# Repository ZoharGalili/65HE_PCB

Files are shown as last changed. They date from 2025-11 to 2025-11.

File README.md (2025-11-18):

# 65HE_PCB

this is a 65% hall effect keyboard pcb running [libhmk](https://github.com/peppapighs/libhmk) firmware.

## Board Renders

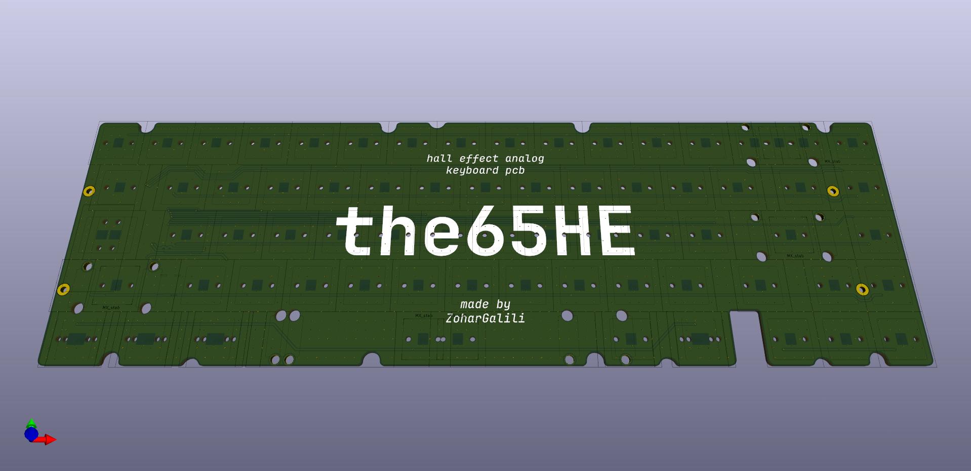
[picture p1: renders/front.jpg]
Render

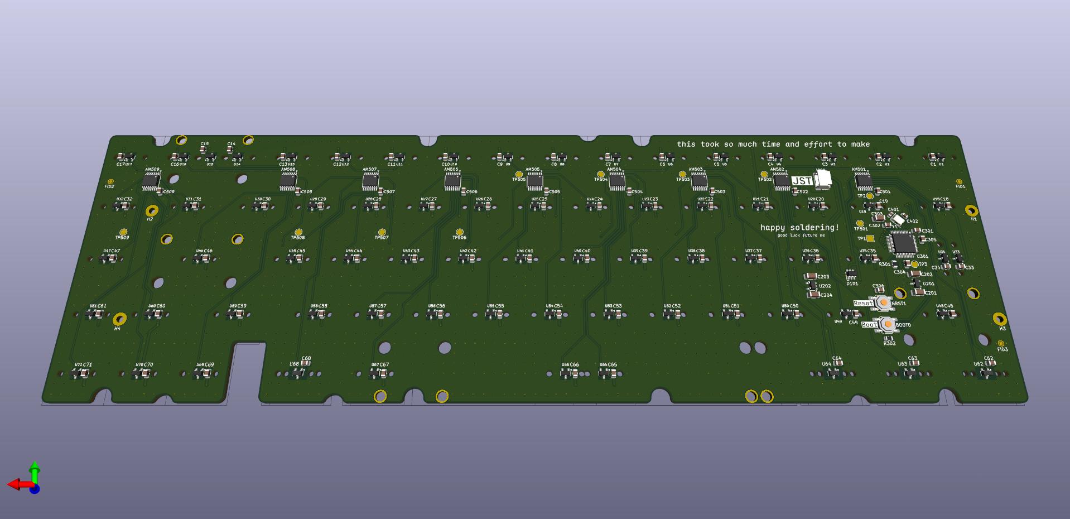
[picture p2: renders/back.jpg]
Render


## Features

- all the usual features of an HE keyboard listed in the [libhmk](https://github.com/peppapighs/libhmk) repo.
- multilayout support (7u/6.25u spacebar, split backspace, stepped caps).
- bakeneko 65 combined with ai03 vega board outline supports gummy o-ring mount.
- at32f405 microcontroller enables 8khz polling rate.
- uses 4 of the ai03 vega outer plate screws.

## Layout

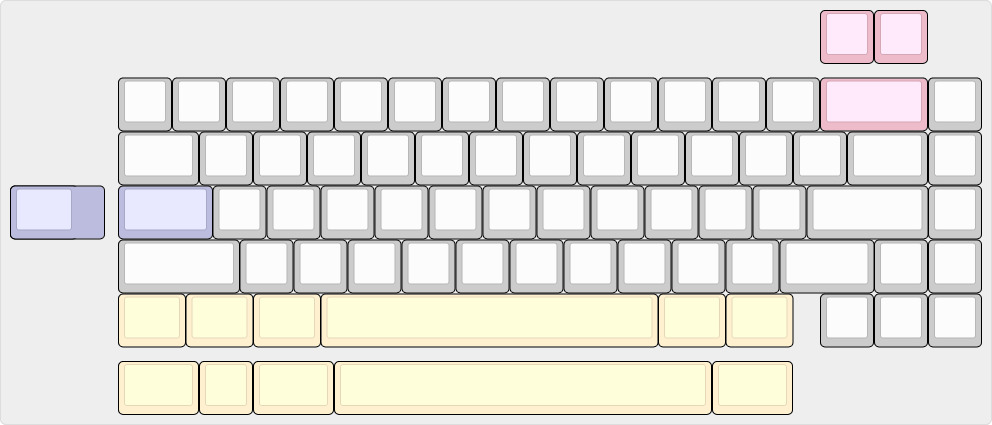
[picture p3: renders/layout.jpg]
Render


### big thanks to peppapighs 

I pretty much coppied the schematic design of the [HE60](https://github.com/peppapighs/HE60) xD

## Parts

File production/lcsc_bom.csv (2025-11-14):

Designator | Footprint | Quantity | Value | LCSC Part #
AM501, AM502, AM503, AM504, AM505, AM506, AM507, AM508, AM509 | TSSOP-16_4.4x5mm_P0.65mm | 9 | SN74LV4051A | C7793
BOOT0, NRST1 | SW_SPST_SKQG_WithStem | 2 | SW_SPST | C318884
C1, C10, C11, C12, C13, C14, C15, C16, C17, C18, C19, C2, C20, C21, C22, C23, C24, C25, C26, C27, C28, C29, C3, C30, C301, C302, C304, C305, C306, C31, C32, C33, C34, C35, C36, C37, C38, C39, C4, C40, C41, C42, C43, C44, C45, C46, C47, C48, C49, C5, C50, C501, C502, C503, C504, C505, C506, C507, C508, C509, C51, C52, C53, C54, C55, C56, C57, C58, C59, C6, C60, C61, C62, C63, C64, C65, C66, C67, C68, C69, C7, C70, C71, C8, C9 | 805 | 85 | 100nF | C5137467
C201, C202, C303 | 1206 | 3 | 1uF | C1848
C203, C204 | 1206 | 2 | 2.2uF | C50254
C401, C402 | 603 | 2 | 30pF | C113797
D101 | SOT-23-6-routable | 1 | SRV05-4 | C2836319
J001 | JST_SH_SM04B-SRSS-TB_1x04-1MP_P1.00mm_Horizontal | 1 | WAFER-SH1.0-4PWB | C3029343
R301, R302 | 805 | 2 | 12kΩ | C114556
U1, U10, U11, U12, U13, U14, U15, U16, U17, U18, U19, U2, U20, U21, U22, U23, U24, U25, U26, U27, U28, U29, U3, U30, U31, U32, U33, U34, U35, U36, U37, U38, U39, U4, U40, U41, U42, U43, U44, U45, U46, U47, U48, U49, U5, U50, U51, U52, U53, U54, U55, U56, U57, U58, U59, U6, U60, U61, U62, U63, U64, U65, U66, U67, U68, U69, U7, U70, U71, U8, U9 | SW_MX_HE_90deg_1u | 71 | SW_MX_HE | C266230
U201 | SOT-23-3 | 1 | XC6206PxxxMR | C347376
U202 | SOT-23-5 | 1 | TLV75733PDBV | C485517
U301 | LQFP-48_7x7mm_P0.5mm | 1 | AT32F405CCT7 | C47115471
Y1 | Crystal_SMD_3225-4Pin_3.2x2.5mm | 1 | X322512MSB4SI | C9002

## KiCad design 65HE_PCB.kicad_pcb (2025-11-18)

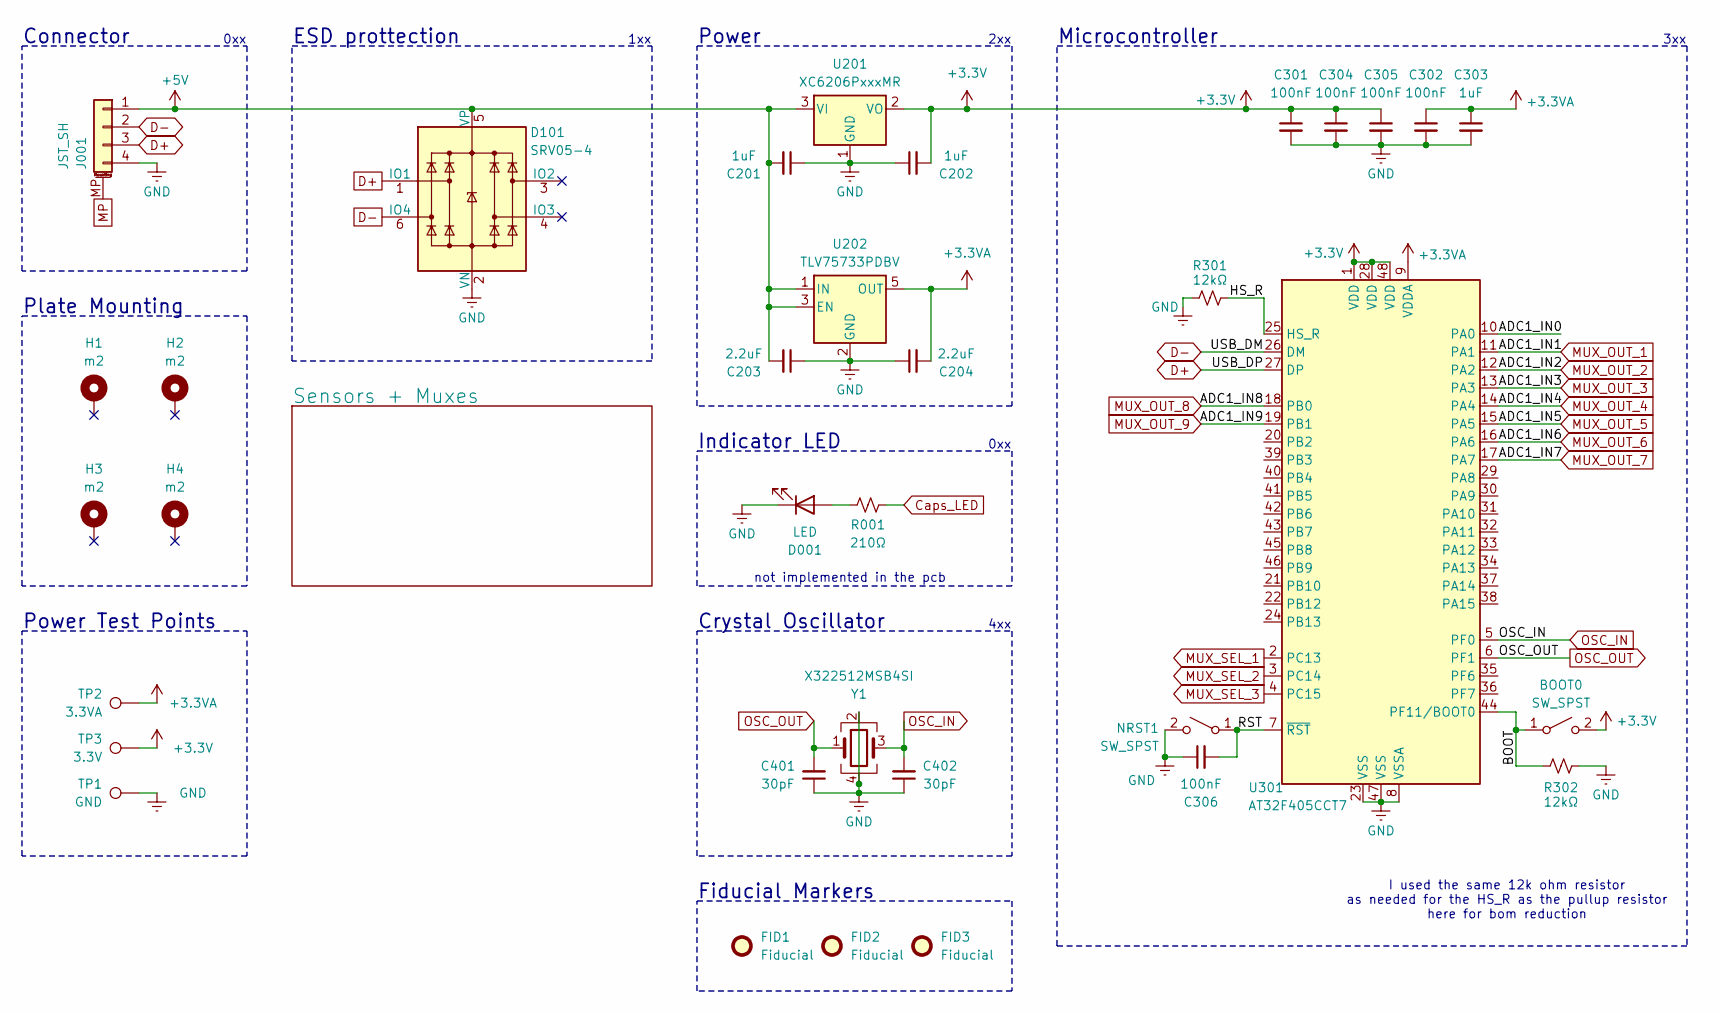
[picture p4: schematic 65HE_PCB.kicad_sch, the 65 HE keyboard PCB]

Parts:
BOOT0: SW_SPST; SW_SPST_SKQG_WithStem
C201, C202, C303: 1uF; C_1206_3216Metric
C203, C204: 2.2uF; C_1206_3216Metric
C301, C302, C304, C305, C306: 100nF; C_0805_2012Metric
C401, C402: 30pF; C_0603_1608Metric
D001: LED; LED_1206_3216Metric_ReverseMount_Hole1.8x2.4mm
D101: SRV05-4; SOT-23-6-routable
FID1, FID2, FID3: Fiducial; Fiducial_1mm_Mask2mm
H1, H2, H3, H4: m2; MountingHole_2.2mm_M2_Pad
J001: JST_SH; JST_SH_SM04B-SRSS-TB_1x04-1MP_P1.00mm_Horizontal
NRST1: SW_SPST; SW_SPST_SKQG_WithStem
R001: 210Ω; R_0805_2012Metric; LCSC C5357171
R301, R302: 12kΩ; R_0805_2012Metric
TP1: GND; TestPoint_Pad_2.0x2.0mm
TP2: 3.3VA; TestPoint_Pad_D2.0mm
TP3: 3.3V; TestPoint_Pad_D2.0mm
U201: XC6206PxxxMR; SOT-23-3
U202: TLV75733PDBV; SOT-23-5
U301: AT32F405CCT7; LQFP-48_7x7mm_P0.5mm
Y1: X322512MSB4SI; Crystal_SMD_3225-4Pin_3.2x2.5mm

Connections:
+3.3V: BOOT0.2 (B), C202.2, C301.1, C304.1, C305.1, TP3.1, U201.2 (VO), U301.1 (VDD), U301.28 (VDD), U301.48 (VDD)
+3.3VA: C204.2, C302.1, C303.1, TP2.1, U202.5 (OUT), U301.9 (VDDA); also elsewhere on the board
+5V: C201.2, C203.2, D101.5 (VP), J001.1, U201.3 (VI), U202.1 (IN), U202.3 (EN)
/ADC1_IN0: U301.10 (PA0)
/BOOT: BOOT0.1 (A), R302.2, U301.44 (PF11/BOOT0)
/HS_R: R301.1, U301.25 (HS_R)
/RST: C306.2, NRST1.1 (A), U301.7 (~RST)
D+: D101.1 (IO1), J001.3, U301.27 (DP)
D-: D101.6 (IO4), J001.2, U301.26 (DM)
GND: C201.1, C202.1, C203.1, C204.1, C301.2, C302.2, C303.2, C304.2, C305.2, C306.1, C401.1, C402.1, D001.1 (K), D101.2 (VN), J001.4, NRST1.2 (B), R301.2, R302.1, TP1.1, U201.1 (GND), U202.2 (GND), U301.8 (VSSA), U301.23 (VSS), U301.47 (VSS), Y1.2, Y1.4; also elsewhere on the board
MP: J001.MP (MountPin)
MUX_OUT_1: U301.11 (PA1); also elsewhere on the board
MUX_OUT_2: U301.12 (PA2); also elsewhere on the board
MUX_OUT_3: U301.13 (PA3); also elsewhere on the board
MUX_OUT_4: U301.14 (PA4); also elsewhere on the board
MUX_OUT_5: U301.15 (PA5); also elsewhere on the board
MUX_OUT_6: U301.16 (PA6); also elsewhere on the board
MUX_OUT_7: U301.17 (PA7); also elsewhere on the board
MUX_OUT_8: U301.18 (PB0); also elsewhere on the board
MUX_OUT_9: U301.19 (PB1); also elsewhere on the board
MUX_SEL_1: U301.2 (PC13); also elsewhere on the board
MUX_SEL_2: U301.3 (PC14); also elsewhere on the board
MUX_SEL_3: U301.4 (PC15); also elsewhere on the board
unnamed: D001.2 (A), R001.1
OSC_IN: C402.2, U301.5 (PF0), Y1.3
OSC_OUT: C401.2, U301.6 (PF1), Y1.1

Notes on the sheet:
Connector
Power Test Points
1xx
2xx
0xx
Plate Mounting
Fiducial Markers
ESD prottection
3xx
Power
not implemented in the pcb
Microcontroller
4xx
I used the same 12k ohm resistor as needed for the HS_R as the pullup resistor here for bom reduction
Indicator LED
Crystal Oscillator

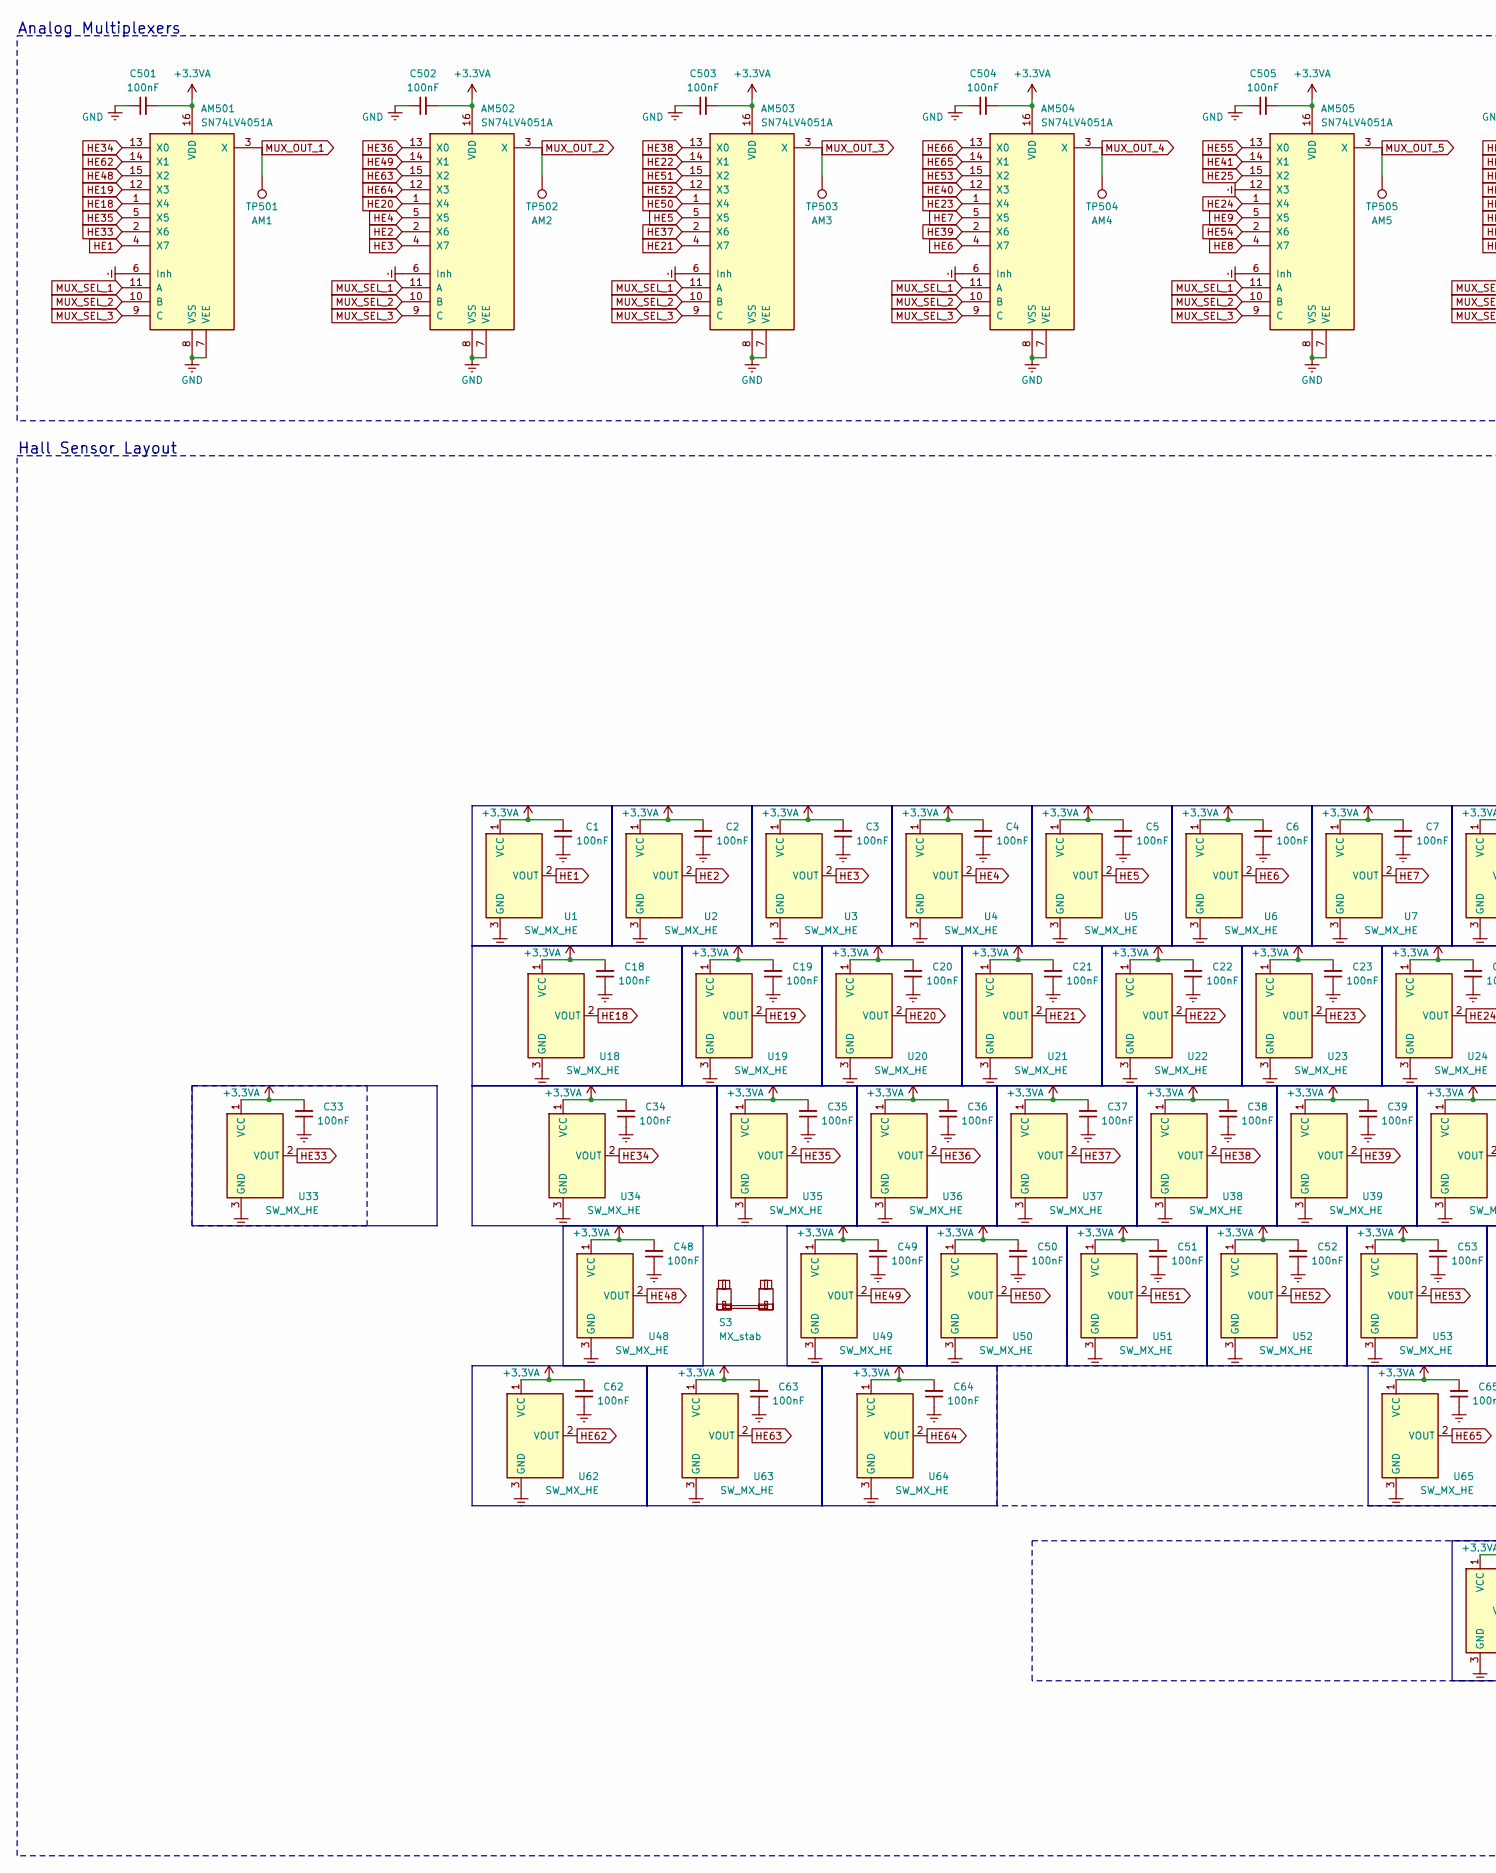
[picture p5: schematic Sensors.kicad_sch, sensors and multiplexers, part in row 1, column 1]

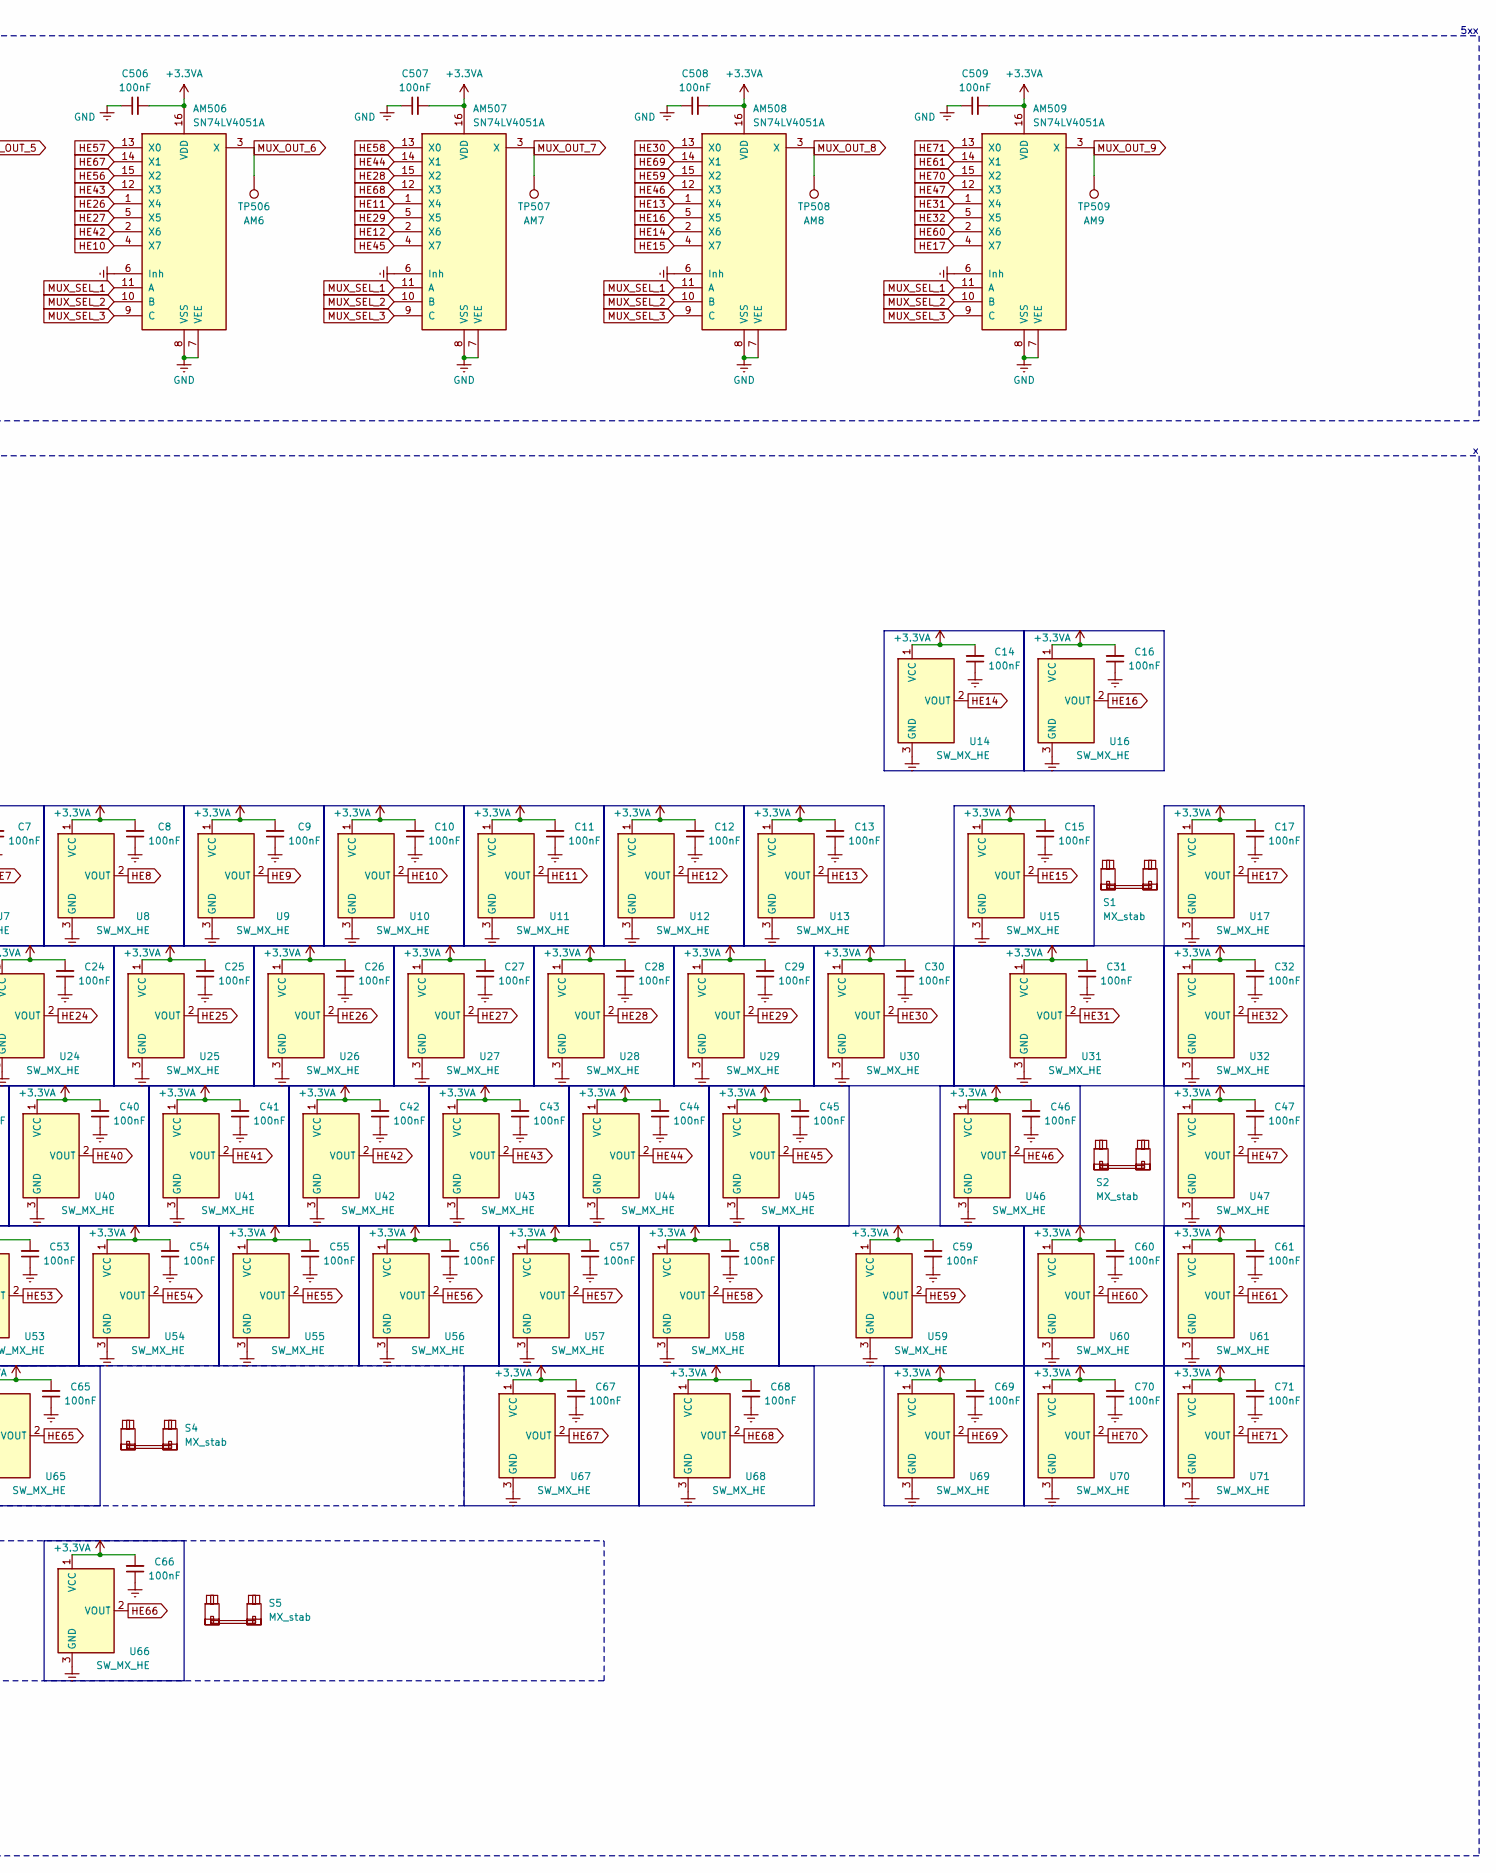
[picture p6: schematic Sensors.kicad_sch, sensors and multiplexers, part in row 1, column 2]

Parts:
AM501, AM502, AM503, AM504, AM505, AM506, AM507, AM508, AM509: SN74LV4051A; TSSOP-16_4.4x5mm_P0.65mm
C1, C2, C3, C4, C5, C6, C7, C8, C9, C10, C11, C12, C13, C14, C15, C16, C17, C18, C19, C20, C21, C22, C23, C24, C25, C26, C27, C28, C29, C30, C31, C32, C33, C34, C35, C36, C37, C38, C39, C40, C41, C42, C43, C44, C45, C46, C47, C48, C49, C50, C51, C52, C53, C54, C55, C56, C57, C58, C59, C60, C61, C62, C63, C64, C65, C66, C67, C68, C69, C70, C71, C501, C502, C503, C504, C505, C506, C507, C508, C509: 100nF; C_0805_2012Metric
S1: MX_stab; STAB_MX_P_2u
S2, S3: MX_stab; STAB_MX_P_2.25u
S4: MX_stab; STAB_MX_P_6.25u
S5: MX_stab; STAB_MX_P_7u
TP501: AM1; TestPoint_Pad_D2.0mm
TP502: AM2; TestPoint_Pad_D2.0mm
TP503: AM3; TestPoint_Pad_D2.0mm
TP504: AM4; TestPoint_Pad_D2.0mm
TP505: AM5; TestPoint_Pad_D2.0mm
TP506: AM6; TestPoint_Pad_D2.0mm
TP507: AM7; TestPoint_Pad_D2.0mm
TP508: AM8; TestPoint_Pad_D2.0mm
TP509: AM9; TestPoint_Pad_D2.0mm
U1, U2, U3, U4, U5, U6, U7, U8, U9, U10, U11, U12, U13, U14, U15, U16, U17, U18, U19, U20, U21, U22, U23, U24, U25, U26, U27, U28, U29, U30, U31, U32, U34, U35, U36, U37, U38, U39, U40, U41, U42, U43, U44, U45, U46, U47, U48, U49, U50, U51, U52, U53, U54, U55, U56, U57, U58, U59, U60, U61, U65, U66, U67, U69, U70, U71: SW_MX_HE; SW_MX_HE_90deg_1u
U33: SW_MX_HE; SW_MX_HE_90deg_1.75u_STP_1.25
U62, U63, U64, U68: SW_MX_HE; SW_MX_HE_90deg_1_8u

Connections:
+3.3VA: AM501.16 (VDD), AM502.16 (VDD), AM503.16 (VDD), AM504.16 (VDD), AM505.16 (VDD), AM506.16 (VDD), AM507.16 (VDD), AM508.16 (VDD), AM509.16 (VDD), C1.2, C2.2, C3.2, C4.2, C5.2, C6.2, C7.2, C8.2, C9.2, C10.2, C11.2, C12.2, C13.2, C14.2, C15.2, C16.2, C17.2, C18.2, C19.2, C20.2, C21.2, C22.2, C23.2, C24.2, C25.2, C26.2, C27.2, C28.2, C29.2, C30.2, C31.2, C32.2, C33.2, C34.2, C35.2, C36.2, C37.2, C38.2, C39.2, C40.2, C41.2, C42.2, C43.2, C44.2, C45.2, C46.2, C47.2, C48.2, C49.2, C50.2, C51.2, C52.2, C53.2, C54.2, C55.2, C56.2, C57.2, C58.2, C59.2, C60.2, C61.2, C62.2, C63.2, C64.2, C65.2, C66.2, C67.2, C68.2, C69.2, C70.2, C71.2, C501.2, C502.2, C503.2, C504.2, C505.2, C506.2, C507.2, C508.2, C509.2, U1.1 (VCC), U2.1 (VCC), U3.1 (VCC), U4.1 (VCC), U5.1 (VCC), U6.1 (VCC), U7.1 (VCC), U8.1 (VCC), U9.1 (VCC), U10.1 (VCC), U11.1 (VCC), U12.1 (VCC), U13.1 (VCC), U14.1 (VCC), U15.1 (VCC), U16.1 (VCC), U17.1 (VCC), U18.1 (VCC), U19.1 (VCC), U20.1 (VCC), U21.1 (VCC), U22.1 (VCC), U23.1 (VCC), U24.1 (VCC), U25.1 (VCC), U26.1 (VCC), U27.1 (VCC), U28.1 (VCC), U29.1 (VCC), U30.1 (VCC), U31.1 (VCC), U32.1 (VCC), U33.1 (VCC), U34.1 (VCC), U35.1 (VCC), U36.1 (VCC), U37.1 (VCC), U38.1 (VCC), U39.1 (VCC), U40.1 (VCC), U41.1 (VCC), U42.1 (VCC), U43.1 (VCC), U44.1 (VCC), U45.1 (VCC), U46.1 (VCC), U47.1 (VCC), U48.1 (VCC), U49.1 (VCC), U50.1 (VCC), U51.1 (VCC), U52.1 (VCC), U53.1 (VCC), U54.1 (VCC), U55.1 (VCC), U56.1 (VCC), U57.1 (VCC), U58.1 (VCC), U59.1 (VCC), U60.1 (VCC), U61.1 (VCC), U62.1 (VCC), U63.1 (VCC), U64.1 (VCC), U65.1 (VCC), U66.1 (VCC), U67.1 (VCC), U68.1 (VCC), U69.1 (VCC), U70.1 (VCC), U71.1 (VCC); also elsewhere on the board
GND: AM501.6 (Inh), AM501.7 (VEE), AM501.8 (VSS), AM502.6 (Inh), AM502.7 (VEE), AM502.8 (VSS), AM503.6 (Inh), AM503.7 (VEE), AM503.8 (VSS), AM504.6 (Inh), AM504.7 (VEE), AM504.8 (VSS), AM505.6 (Inh), AM505.7 (VEE), AM505.8 (VSS), AM505.12 (X3), AM506.6 (Inh), AM506.7 (VEE), AM506.8 (VSS), AM507.6 (Inh), AM507.7 (VEE), AM507.8 (VSS), AM508.6 (Inh), AM508.7 (VEE), AM508.8 (VSS), AM509.6 (Inh), AM509.7 (VEE), AM509.8 (VSS), C1.1, C2.1, C3.1, C4.1, C5.1, C6.1, C7.1, C8.1, C9.1, C10.1, C11.1, C12.1, C13.1, C14.1, C15.1, C16.1, C17.1, C18.1, C19.1, C20.1, C21.1, C22.1, C23.1, C24.1, C25.1, C26.1, C27.1, C28.1, C29.1, C30.1, C31.1, C32.1, C33.1, C34.1, C35.1, C36.1, C37.1, C38.1, C39.1, C40.1, C41.1, C42.1, C43.1, C44.1, C45.1, C46.1, C47.1, C48.1, C49.1, C50.1, C51.1, C52.1, C53.1, C54.1, C55.1, C56.1, C57.1, C58.1, C59.1, C60.1, C61.1, C62.1, C63.1, C64.1, C65.1, C66.1, C67.1, C68.1, C69.1, C70.1, C71.1, C501.1, C502.1, C503.1, C504.1, C505.1, C506.1, C507.1, C508.1, C509.1, U1.3 (GND), U2.3 (GND), U3.3 (GND), U4.3 (GND), U5.3 (GND), U6.3 (GND), U7.3 (GND), U8.3 (GND), U9.3 (GND), U10.3 (GND), U11.3 (GND), U12.3 (GND), U13.3 (GND), U14.3 (GND), U15.3 (GND), U16.3 (GND), U17.3 (GND), U18.3 (GND), U19.3 (GND), U20.3 (GND), U21.3 (GND), U22.3 (GND), U23.3 (GND), U24.3 (GND), U25.3 (GND), U26.3 (GND), U27.3 (GND), U28.3 (GND), U29.3 (GND), U30.3 (GND), U31.3 (GND), U32.3 (GND), U33.3 (GND), U34.3 (GND), U35.3 (GND), U36.3 (GND), U37.3 (GND), U38.3 (GND), U39.3 (GND), U40.3 (GND), U41.3 (GND), U42.3 (GND), U43.3 (GND), U44.3 (GND), U45.3 (GND), U46.3 (GND), U47.3 (GND), U48.3 (GND), U49.3 (GND), U50.3 (GND), U51.3 (GND), U52.3 (GND), U53.3 (GND), U54.3 (GND), U55.3 (GND), U56.3 (GND), U57.3 (GND), U58.3 (GND), U59.3 (GND), U60.3 (GND), U61.3 (GND), U62.3 (GND), U63.3 (GND), U64.3 (GND), U65.3 (GND), U66.3 (GND), U67.3 (GND), U68.3 (GND), U69.3 (GND), U70.3 (GND), U71.3 (GND); also elsewhere on the board
HE1: AM501.4 (X7), U1.2 (VOUT)
HE2: AM502.2 (X6), U2.2 (VOUT)
HE3: AM502.4 (X7), U3.2 (VOUT)
HE4: AM502.5 (X5), U4.2 (VOUT)
HE5: AM503.5 (X5), U5.2 (VOUT)
HE6: AM504.4 (X7), U6.2 (VOUT)
HE7: AM504.5 (X5), U7.2 (VOUT)
HE8: AM505.4 (X7), U8.2 (VOUT)
HE9: AM505.5 (X5), U9.2 (VOUT)
HE10: AM506.4 (X7), U10.2 (VOUT)
HE11: AM507.1 (X4), U11.2 (VOUT)
HE12: AM507.2 (X6), U12.2 (VOUT)
HE13: AM508.1 (X4), U13.2 (VOUT)
HE14: AM508.2 (X6), U14.2 (VOUT)
HE15: AM508.4 (X7), U15.2 (VOUT)
HE16: AM508.5 (X5), U16.2 (VOUT)
HE17: AM509.4 (X7), U17.2 (VOUT)
HE18: AM501.1 (X4), U18.2 (VOUT)
HE19: AM501.12 (X3), U19.2 (VOUT)
HE20: AM502.1 (X4), U20.2 (VOUT)
HE21: AM503.4 (X7), U21.2 (VOUT)
HE22: AM503.14 (X1), U22.2 (VOUT)
HE23: AM504.1 (X4), U23.2 (VOUT)
HE24: AM505.1 (X4), U24.2 (VOUT)
HE25: AM505.15 (X2), U25.2 (VOUT)
HE26: AM506.1 (X4), U26.2 (VOUT)
HE27: AM506.5 (X5), U27.2 (VOUT)
HE28: AM507.15 (X2), U28.2 (VOUT)
HE29: AM507.5 (X5), U29.2 (VOUT)
HE30: AM508.13 (X0), U30.2 (VOUT)
HE31: AM509.1 (X4), U31.2 (VOUT)
HE32: AM509.5 (X5), U32.2 (VOUT)
HE33: AM501.2 (X6), U33.2 (VOUT)
HE34: AM501.13 (X0), U34.2 (VOUT)
HE35: AM501.5 (X5), U35.2 (VOUT)
HE36: AM502.13 (X0), U36.2 (VOUT)
HE37: AM503.2 (X6), U37.2 (VOUT)
HE38: AM503.13 (X0), U38.2 (VOUT)
HE39: AM504.2 (X6), U39.2 (VOUT)
HE40: AM504.12 (X3), U40.2 (VOUT)
HE41: AM505.14 (X1), U41.2 (VOUT)
HE42: AM506.2 (X6), U42.2 (VOUT)
HE43: AM506.12 (X3), U43.2 (VOUT)
HE44: AM507.14 (X1), U44.2 (VOUT)
HE45: AM507.4 (X7), U45.2 (VOUT)
HE46: AM508.12 (X3), U46.2 (VOUT)
HE47: AM509.12 (X3), U47.2 (VOUT)
HE48: AM501.15 (X2), U48.2 (VOUT)
HE49: AM502.14 (X1), U49.2 (VOUT)
HE50: AM503.1 (X4), U50.2 (VOUT)
HE51: AM503.15 (X2), U51.2 (VOUT)
HE52: AM503.12 (X3), U52.2 (VOUT)
HE53: AM504.15 (X2), U53.2 (VOUT)
HE54: AM505.2 (X6), U54.2 (VOUT)
HE55: AM505.13 (X0), U55.2 (VOUT)
HE56: AM506.15 (X2), U56.2 (VOUT)
HE57: AM506.13 (X0), U57.2 (VOUT)
HE58: AM507.13 (X0), U58.2 (VOUT)
HE59: AM508.15 (X2), U59.2 (VOUT)
HE60: AM509.2 (X6), U60.2 (VOUT)
HE61: AM509.14 (X1), U61.2 (VOUT)
HE62: AM501.14 (X1), U62.2 (VOUT)
HE63: AM502.15 (X2), U63.2 (VOUT)
HE64: AM502.12 (X3), U64.2 (VOUT)
HE65: AM504.14 (X1), U65.2 (VOUT)
HE66: AM504.13 (X0), U66.2 (VOUT)
HE67: AM506.14 (X1), U67.2 (VOUT)
HE68: AM507.12 (X3), U68.2 (VOUT)
HE69: AM508.14 (X1), U69.2 (VOUT)
HE70: AM509.15 (X2), U70.2 (VOUT)
HE71: AM509.13 (X0), U71.2 (VOUT)
MUX_OUT_1: AM501.3 (X), TP501.1; also elsewhere on the board
MUX_OUT_2: AM502.3 (X), TP502.1; also elsewhere on the board
MUX_OUT_3: AM503.3 (X), TP503.1; also elsewhere on the board
MUX_OUT_4: AM504.3 (X), TP504.1; also elsewhere on the board
MUX_OUT_5: AM505.3 (X), TP505.1; also elsewhere on the board
MUX_OUT_6: AM506.3 (X), TP506.1; also elsewhere on the board
MUX_OUT_7: AM507.3 (X), TP507.1; also elsewhere on the board
MUX_OUT_8: AM508.3 (X), TP508.1; also elsewhere on the board
MUX_OUT_9: AM509.3 (X), TP509.1; also elsewhere on the board
MUX_SEL_1: AM501.11 (A), AM502.11 (A), AM503.11 (A), AM504.11 (A), AM505.11 (A), AM506.11 (A), AM507.11 (A), AM508.11 (A), AM509.11 (A); also elsewhere on the board
MUX_SEL_2: AM501.10 (B), AM502.10 (B), AM503.10 (B), AM504.10 (B), AM505.10 (B), AM506.10 (B), AM507.10 (B), AM508.10 (B), AM509.10 (B); also elsewhere on the board
MUX_SEL_3: AM501.9 (C), AM502.9 (C), AM503.9 (C), AM504.9 (C), AM505.9 (C), AM506.9 (C), AM507.9 (C), AM508.9 (C), AM509.9 (C); also elsewhere on the board

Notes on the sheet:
5xx
Analog Multiplexers
Hall Sensor Layout

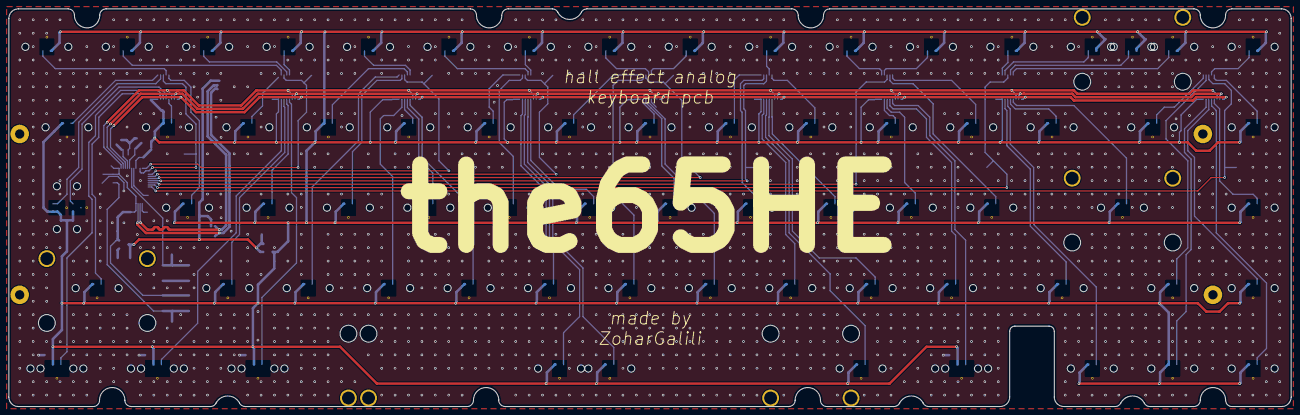
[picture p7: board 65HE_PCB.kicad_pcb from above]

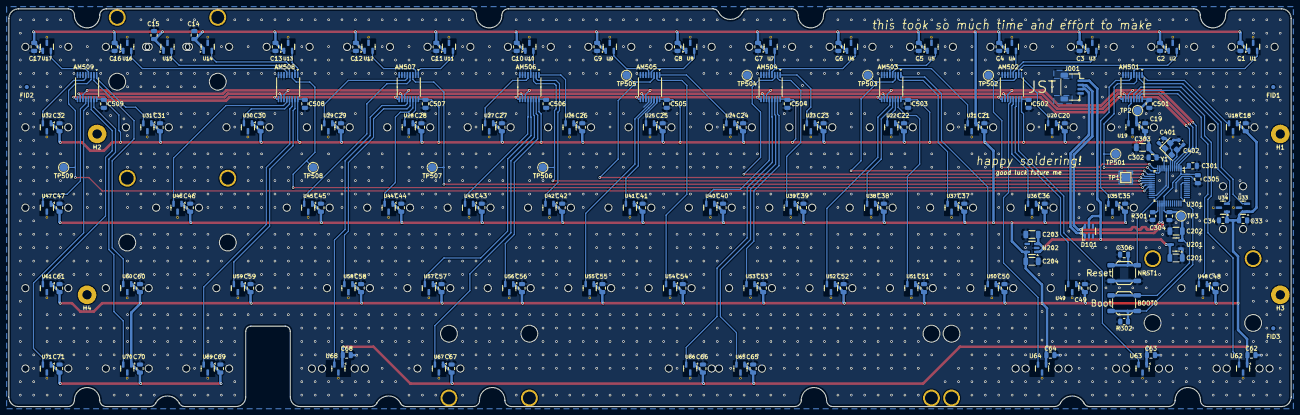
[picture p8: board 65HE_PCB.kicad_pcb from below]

Board: 2 copper layers, 303.8 x 94.2 mm, 206 parts (201 on the bottom side), 94 nets.

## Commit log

2025-10-04 initial commit
    i made the board yay!
    [65HE_PCB.kicad_sch, Sensors.kicad_sch, bom.csv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]
2025-10-06 no rounded tracks
    routed the pcb again but without rounding the tracks because kicad became laggy af
    [65HE_PCB.kicad_sch, Sensors.kicad_sch]
2025-10-10 full PCB and BOM
    the pcb is done (i hope) and i made the production files and filled out the bom with parts from lcsc
    [65HE_PCB.kicad_pcb, Sensors.kicad_sch, bom.csv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]
2025-11-14 1 less multiplexer!
    made the whole board again to use only 1 sensor for each 1/8 unit pair of switches on the bottom row. i also made some improvements in the whole design itself
    [65HE_PCB.kicad_pcb, 65HE_PCB.kicad_sch, Sensors.kicad_sch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]
2025-11-15 polished up the board and readme
    added silckscreen to the board and filled out the readme with some basic information
    [65HE_PCB.kicad_pcb, lcsc_bom.csv]
2025-11-18 added test points
    added test points to the pcb power lines and multiplexer outputs, hopefully the readme is fixed as well
    [65HE_PCB.kicad_pcb, 65HE_PCB.kicad_sch, Sensors.kicad_sch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]
